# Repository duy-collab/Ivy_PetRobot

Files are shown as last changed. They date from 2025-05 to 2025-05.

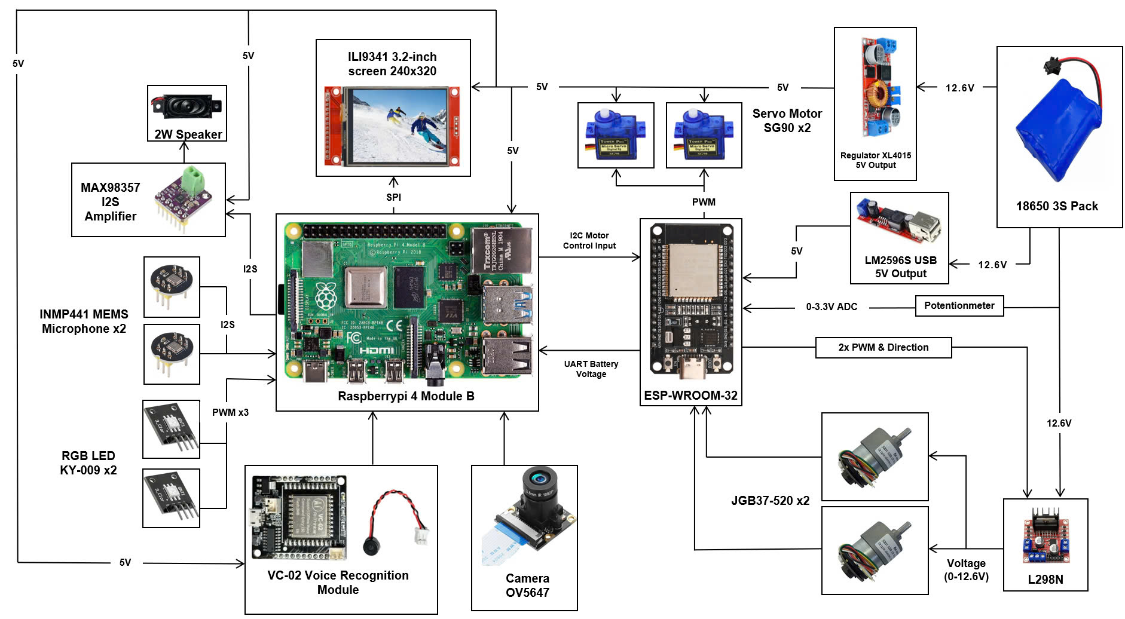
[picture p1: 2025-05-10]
HARDWARE SYSTEM.jpg

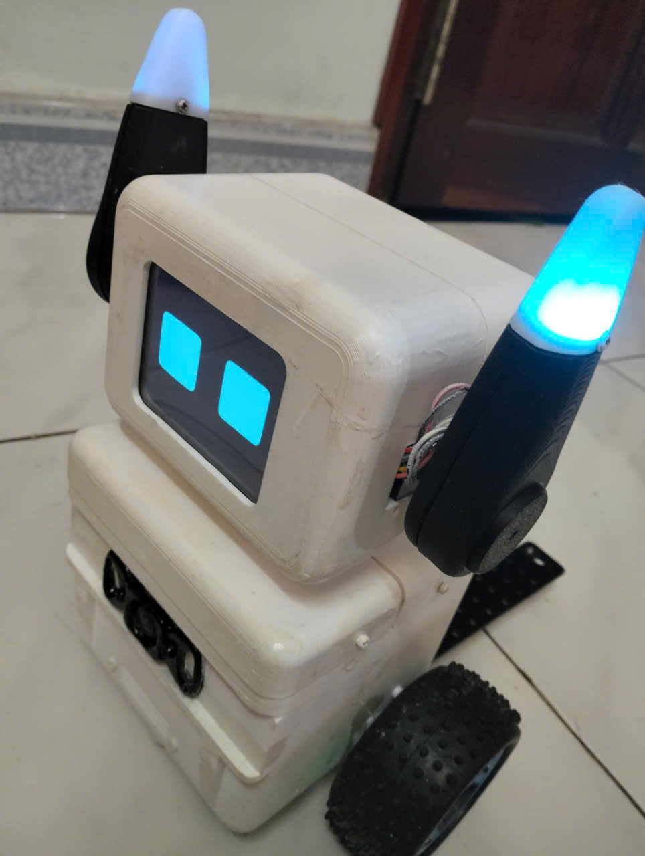
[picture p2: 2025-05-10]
Ivy_Pics/1.jpg

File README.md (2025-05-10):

# Ivy_PetRobot

Ivy_PetRobot is an interactive AI-powered pet robot designed to engage with users through voice, facial recognition, and dynamic behaviors. It brings personality to robotics with a focus on emotional expression and smart interaction.

## Features

- 🎤 Voice recognition using Whisper
- 🗣️ Speech synthesis with natural voice
- 🧠 AI-powered conversation using OpenAI API
- 📷 Image recognition and scene description
- 😺 Facial emotion display via LCD and LED
- 🛞 Motor control for mobility and animation
- 🕹️ ESP32 & Raspberry Pi integration
- 📡 MQTT cloud communication with HiveMQ
- 📁 I2C communication for command synchronization

## Technologies Used

- Raspberry Pi OS Bullseye
- ESP32 microcontroller
- INMP441 microphone (I2S)
- MAX98357A speaker amp (I2S)
- ILI9341 / ST7796 LCD with GT911 touch
- OpenAI Whisper and GPT APIs
- HiveMQ MQTT for IoT data streaming
- Python, C++ (Arduino), Bash

## Repository Structure

/Ivy_PetRobot
├── raspberry_pi/ # Main AI logic, image processing, audio I/O

├── esp32/ # Display, motors, expression handling

├── arduino_nano/ # Optional: audio capture and I2C transmission

├── assets/ # Face expression images, sound files

├── docs/ # Reports and design documentation

└── README.md

## Credits

Final year thesis project by Luong Ho Khanh Duy, Student ID 2113013 and Tran Kim Khanh, Student ID 2113717 — Department of Electrical Engineering, Ho Chi Minh City University of Technology (HCMUT).

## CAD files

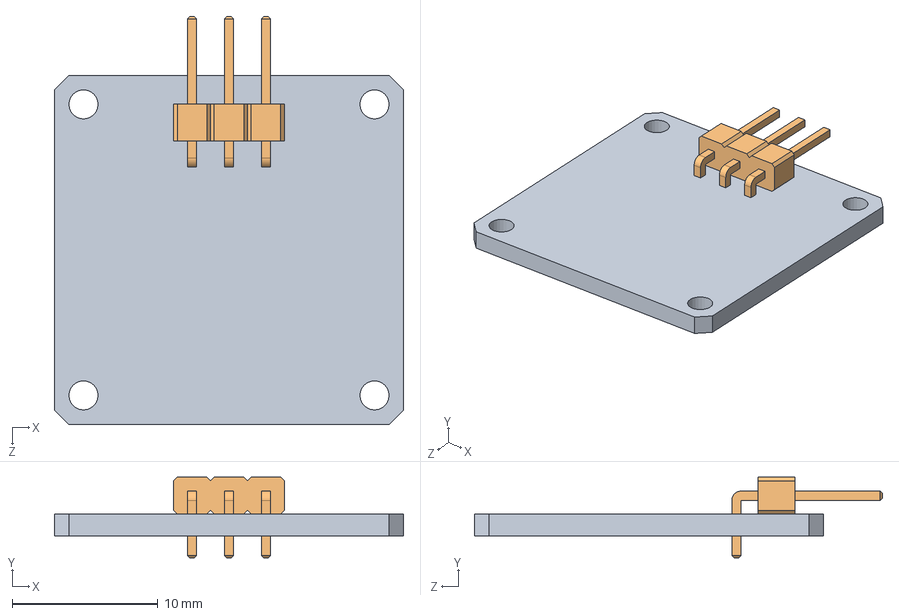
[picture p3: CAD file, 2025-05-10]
Ivy_SolidWorks/HEAD/TTP223B_with_header.SLDASM
24.0 x 5.54 x 28.0 mm
TTP223B
PinHeader_1x03_P2.54mm_Horizontal

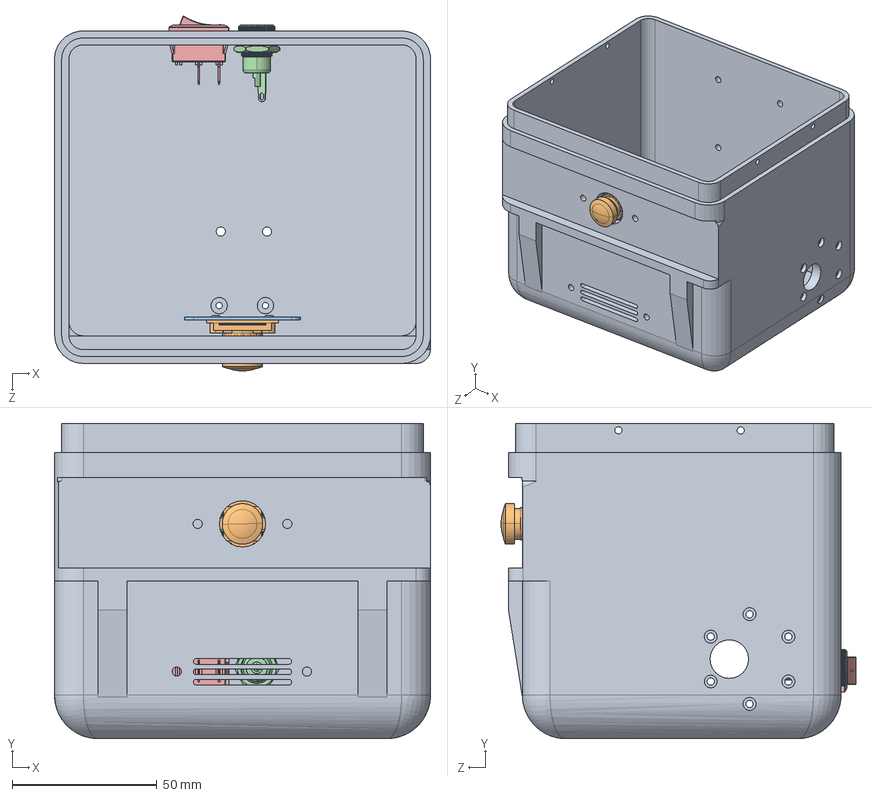
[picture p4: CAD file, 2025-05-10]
Ivy_SolidWorks/BODY/Body_Full.SLDASM
130.0 x 109.0 x 122.7 mm
camera_OV5647
camera_OV5647_mount
charging_port_5.5_2.1_DC
KCD1-101_2pin

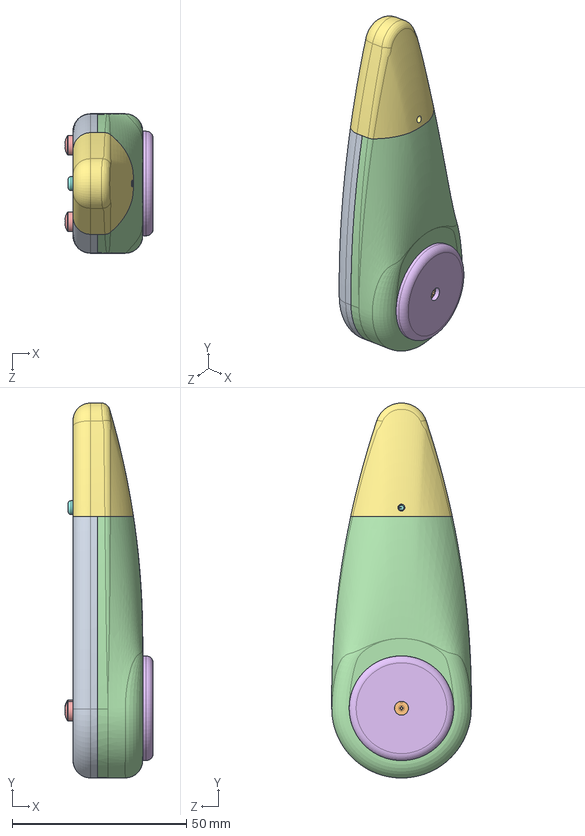
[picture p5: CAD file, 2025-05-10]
Ivy_SolidWorks/HEAD/EAR/EAR_FULL.SLDASM
25.4 x 107.5 x 40.0 mm
Inside_Ear
new_ear_pcb
spacer_10mm x 2
Outside_Ear
pan head cross recess screw_iso x 4
new_mic_cover
Top_Ear
pan head tapping screw_am

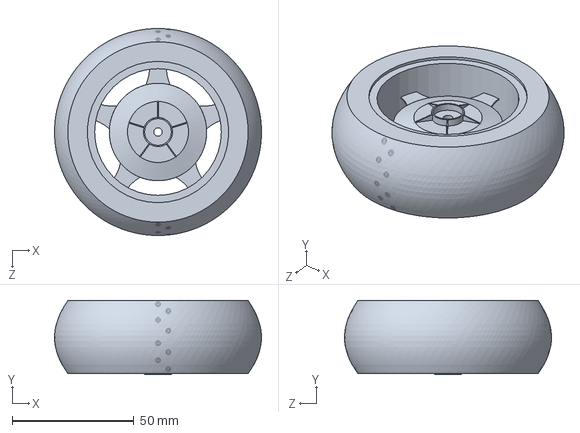
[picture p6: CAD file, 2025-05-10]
Ivy_SolidWorks/WHEEL/Wheel_assem.SLDASM
85.0 x 30.4 x 85.0 mm
85mm_Wheel
wheel_adapter

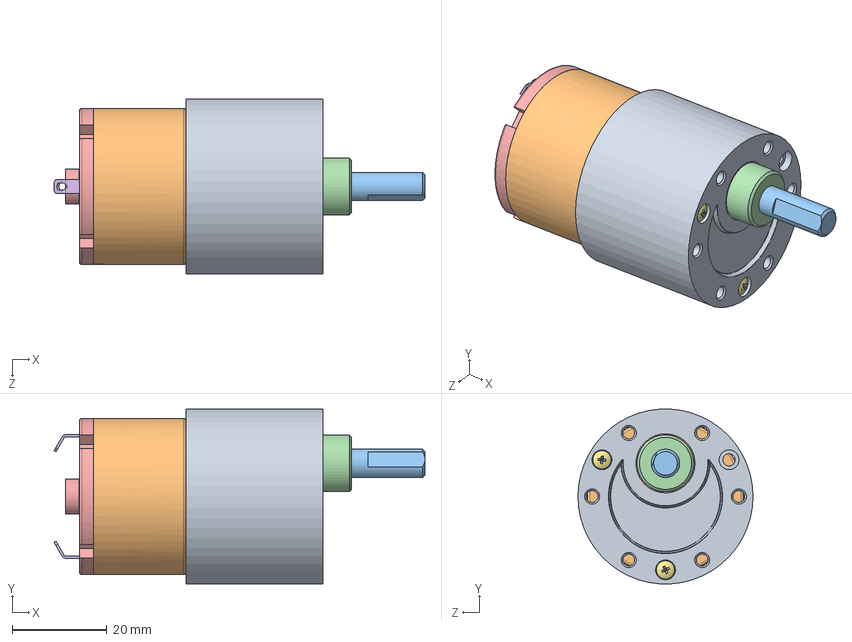
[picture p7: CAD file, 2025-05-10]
Ivy_SolidWorks/WHEEL/JGA37_520.SLDASM
78.4 x 36.9 x 37.0 mm
GEARED BODY, MOTOR, JGB37-520
DC MOTOR, JGB37-520
MOTOR SHAFT, JGB37-520
SHAFT COUPLER, JGB37-520
PLASTIC COVER, DC MOTOR, JGB37-520
CONNECTION, DC MOTOR, JGB37-520 x 2
pan cross head_am x 2

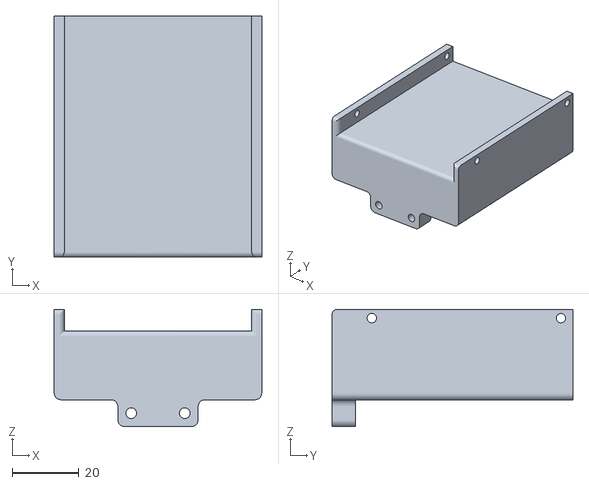
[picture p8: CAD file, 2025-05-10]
Ivy_PRINT_3D/power_shell.STL
62.0 x 72.0 x 35.0

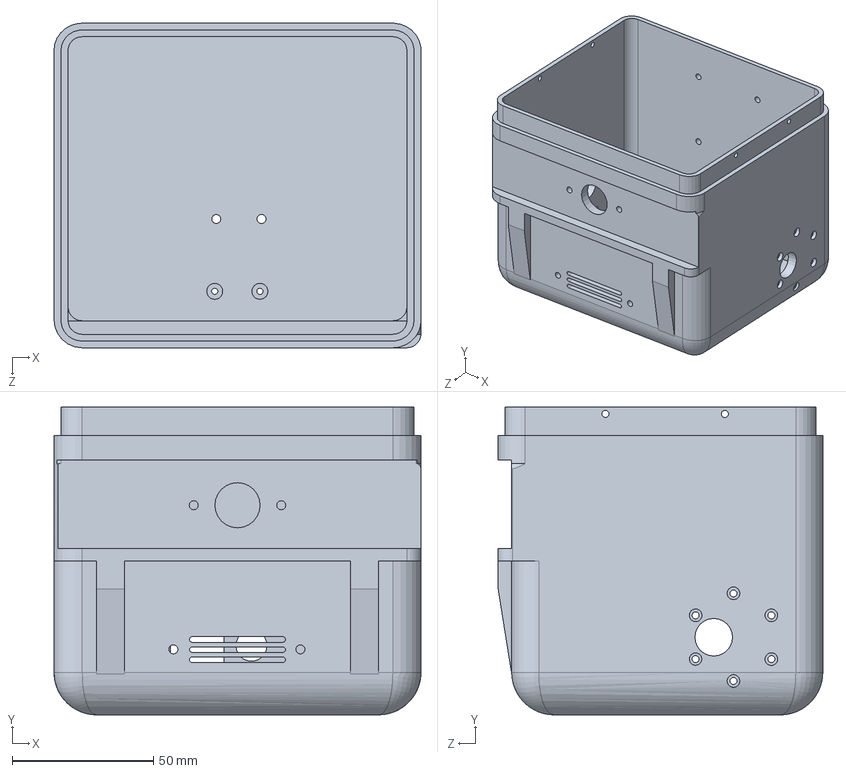
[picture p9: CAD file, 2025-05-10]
Ivy_SolidWorks/BODY/Body.SLDPRT
130.0 x 109.0 x 115.0 mm

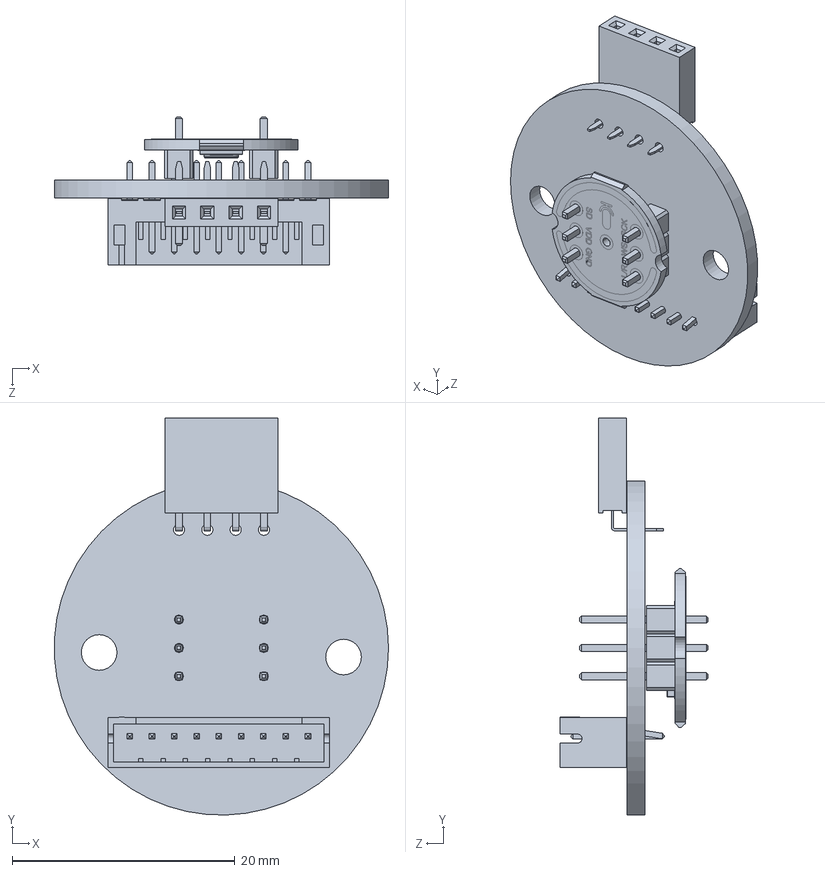
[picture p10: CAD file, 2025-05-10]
Ivy_SolidWorks/HEAD/EAR/new_ear_pcb.SLDPRT
30.0 x 35.6 x 13.3 mm

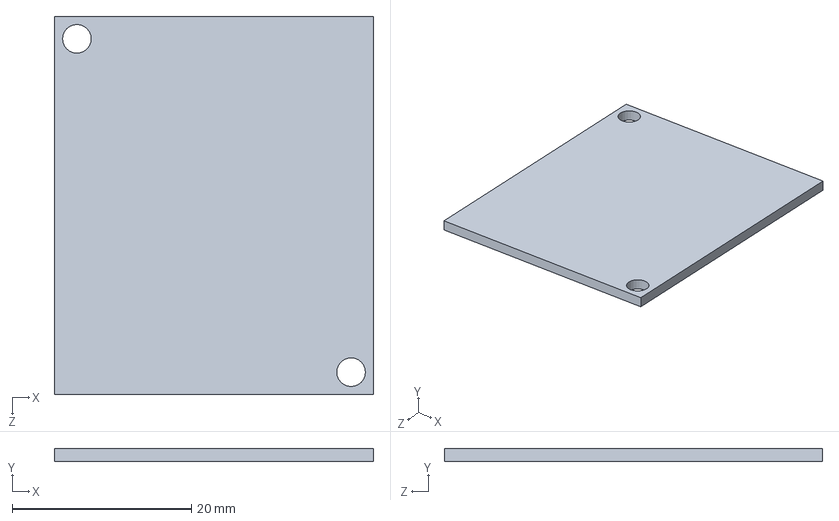
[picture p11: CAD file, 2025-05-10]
Ivy_SolidWorks/HEAD/VC-02.SLDPRT
35.6 x 1.50 x 42.2 mm

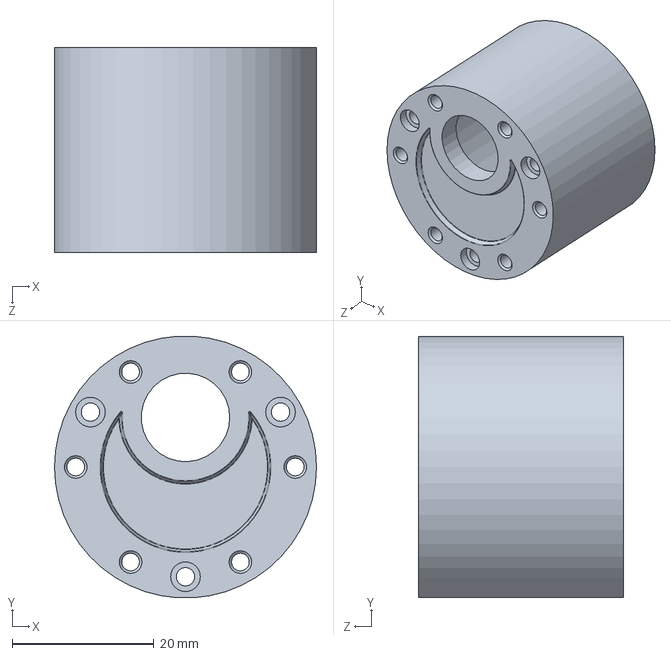
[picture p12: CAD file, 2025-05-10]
Ivy_SolidWorks/WHEEL/GEARED BODY, MOTOR, JGB37-520.SLDPRT
37.0 x 36.9 x 29.0 mm

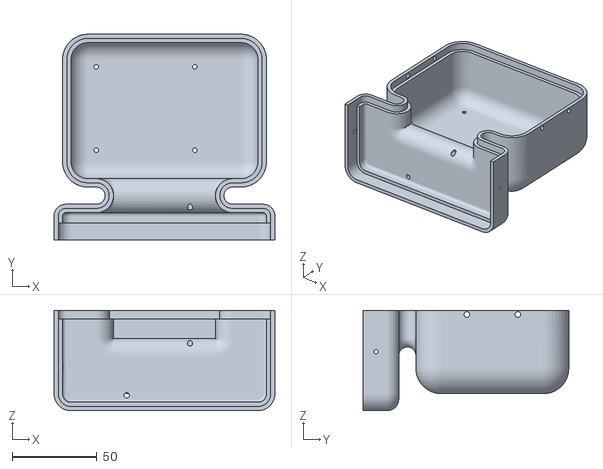
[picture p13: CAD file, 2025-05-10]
Ivy_PRINT_3D/BackHead.STL
130.0 x 121.0 x 59.1

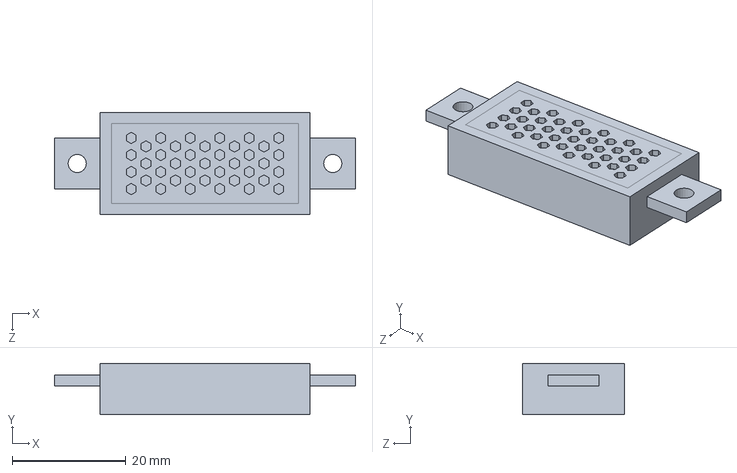
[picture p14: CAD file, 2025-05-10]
Ivy_SolidWorks/BODY/speaker_2w.SLDPRT
53.0 x 9.00 x 18.0 mm

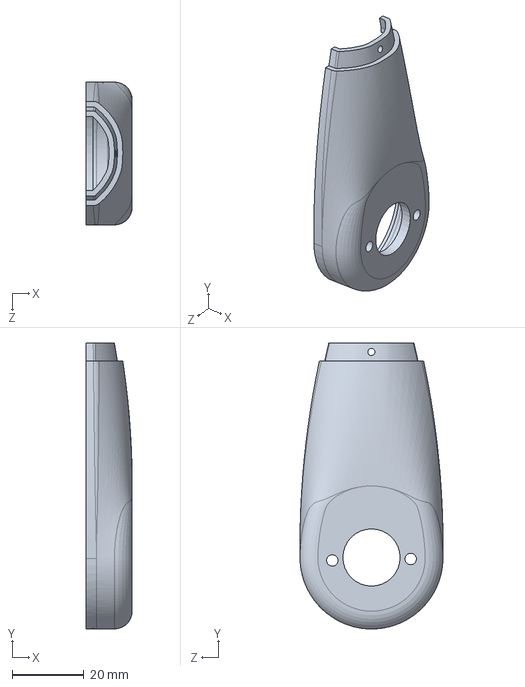
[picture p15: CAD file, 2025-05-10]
Ivy_SolidWorks/HEAD/EAR/Outside_Ear.SLDPRT
13.0 x 80.0 x 40.0 mm

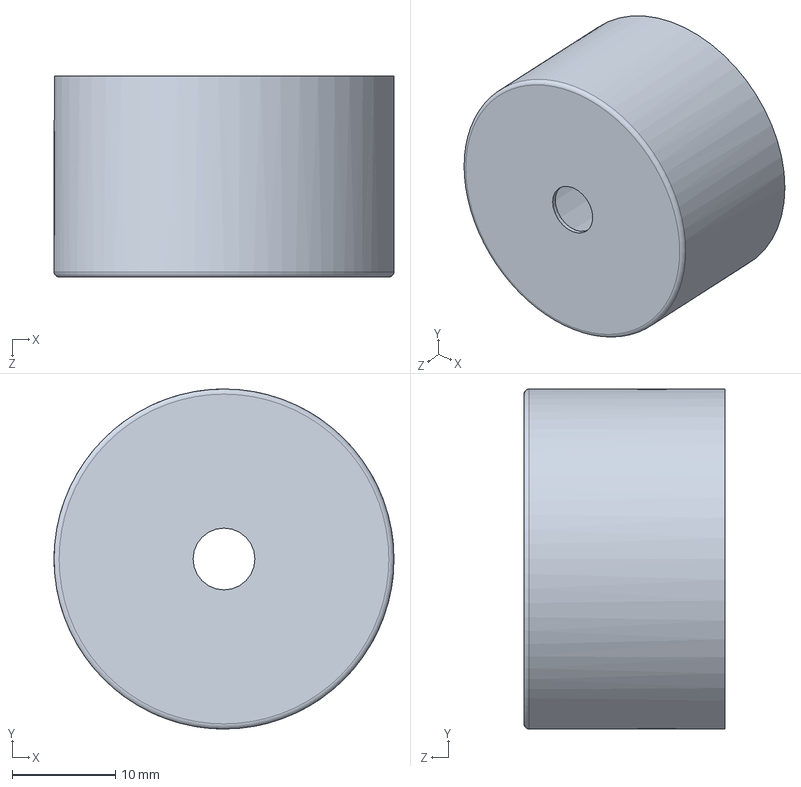
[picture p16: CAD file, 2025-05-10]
Ivy_SolidWorks/WHEEL/DC MOTOR, JGB37-520.SLDPRT
33.0 x 33.0 x 19.5 mm

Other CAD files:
Ivy_SolidWorks/BODY/Battery/power_shell.SLDPRT
Ivy_PRINT_3D/camera_OV5647_mount.STL
Ivy_SolidWorks/HEAD/EAR/Top_Ear.SLDPRT
Ivy_SolidWorks/HEAD/PinHeader_1x03_P2.54mm_Horizontal.SLDPRT
Ivy_PRINT_3D/Body_ver2_22-9.STL
Ivy_PRINT_3D/FrontHead.STL
Ivy_PRINT_3D/TAI_NGOAI.STL
Ivy_PRINT_3D/TAI_TOP.STL
Ivy_PRINT_3D/TAI_TRONG.STL
Ivy_PRINT_3D/bowtie.STL
Ivy_PRINT_3D/new_mic_cover.STL
Ivy_SolidWorks/BODY/L298N.SLDPRT
Ivy_SolidWorks/BODY/bowtie.SLDPRT
Ivy_SolidWorks/BODY/camera_OV5647.SLDPRT
Ivy_SolidWorks/BODY/camera_OV5647_mount.SLDPRT
Ivy_SolidWorks/BODY/caster_ball.SLDPRT
Ivy_SolidWorks/BODY/charging_port_5.5_2.1_DC.SLDPRT
Ivy_SolidWorks/HEAD/Back_Head.SLDPRT
Ivy_SolidWorks/HEAD/EAR/Inside_Ear.SLDPRT
Ivy_SolidWorks/HEAD/EAR/ear_mica_holder.SLDPRT
Ivy_SolidWorks/HEAD/EAR/new_mic_cover.SLDPRT
Ivy_SolidWorks/HEAD/EAR/sg90_horn.SLDPRT
Ivy_SolidWorks/HEAD/EAR/spacer_10mm.SLDPRT
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

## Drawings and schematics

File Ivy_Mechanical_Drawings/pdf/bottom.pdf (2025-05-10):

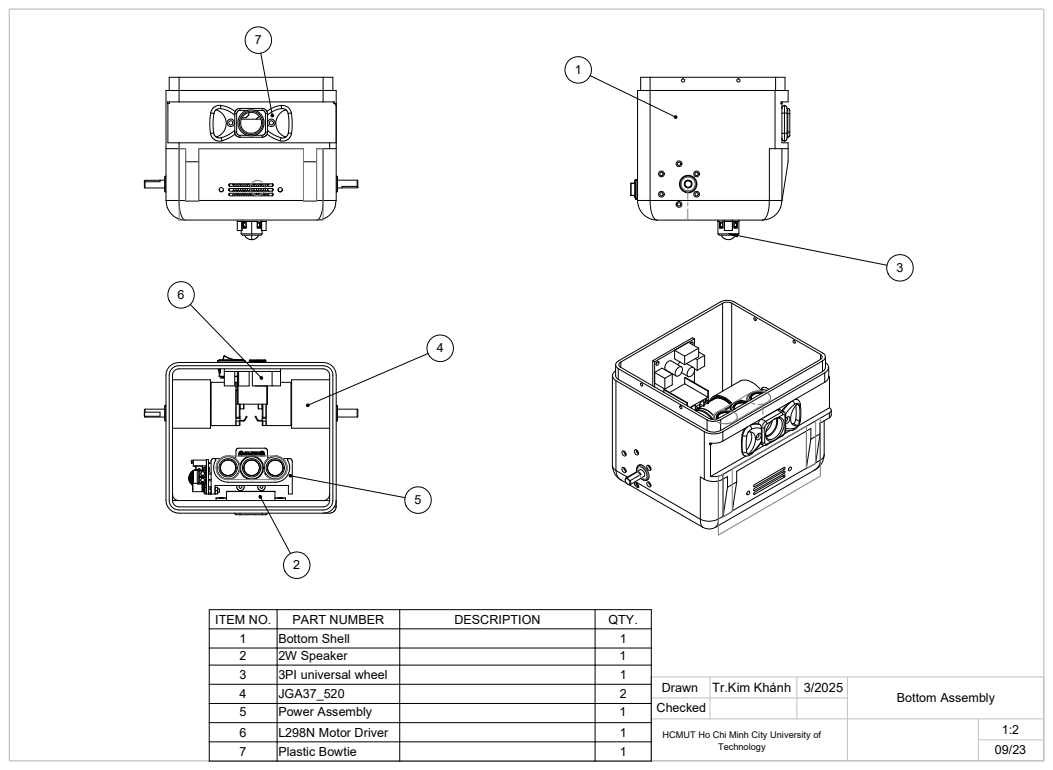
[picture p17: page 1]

ITEM NO. | PART NUMBER | DESCRIPTION | QTY.
1 | Bottom Shell | | 1
2 | 2W Speaker | | 1
3 | 3PI universal wheel | | 1
4 | JGA37_520 | | 2
5 | Power Assembly | | 1
6 | L298N Motor Driver | | 1
7 | Plastic Bowtie | | 1 | 09/23

Drawn | Tr.Kim Khánh | 3/2025 | Bottom Assembly
Checked

HCMUT Ho Chi Minh City University of Technology | | 1:2

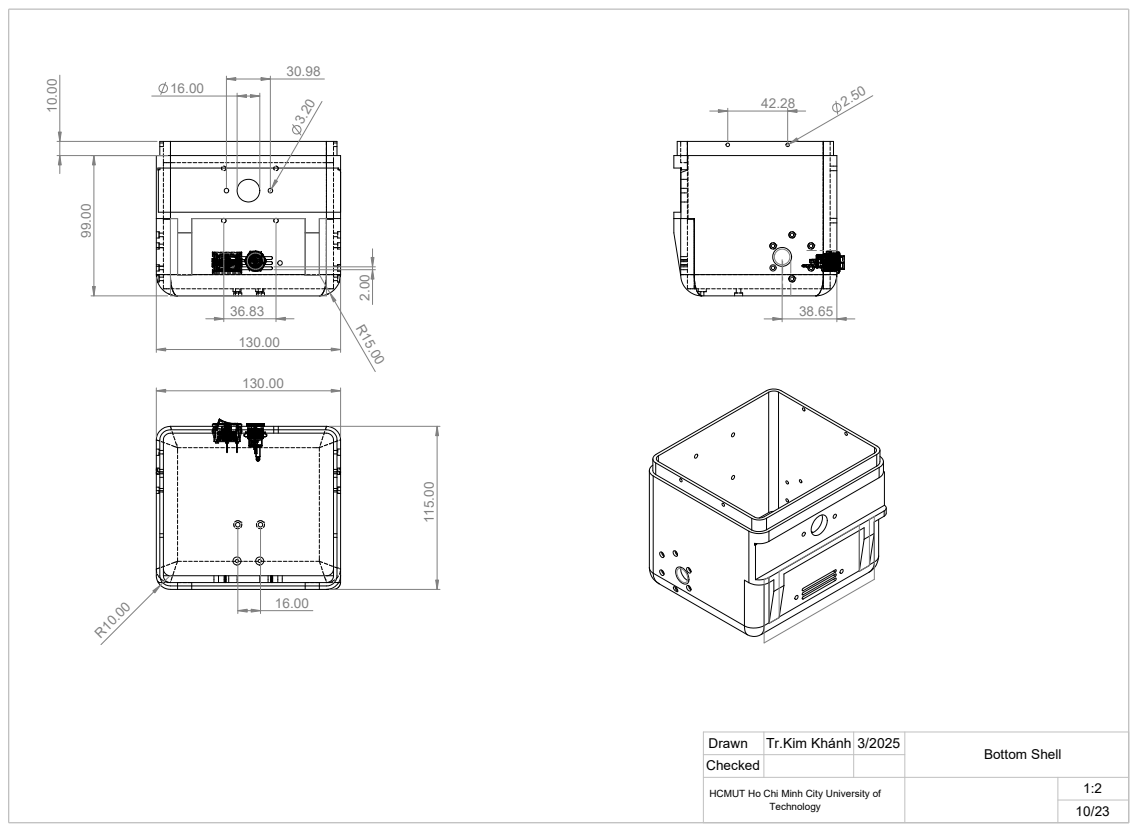
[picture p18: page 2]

Drawn | Tr.Kim Khánh | 3/2025 | Bottom Shell
Checked

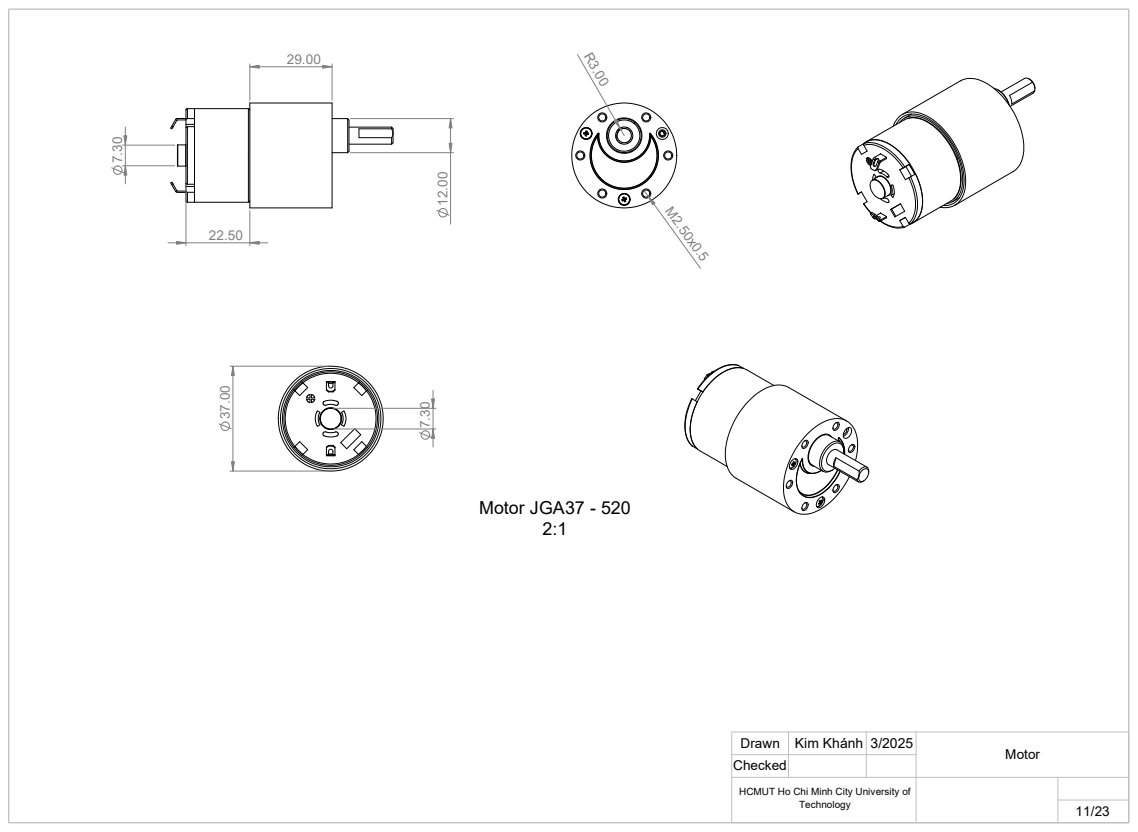
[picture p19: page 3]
Technology; Motor JGA37 - 520

Drawn | Kim Khánh | 3/2025 | Motor
Checked

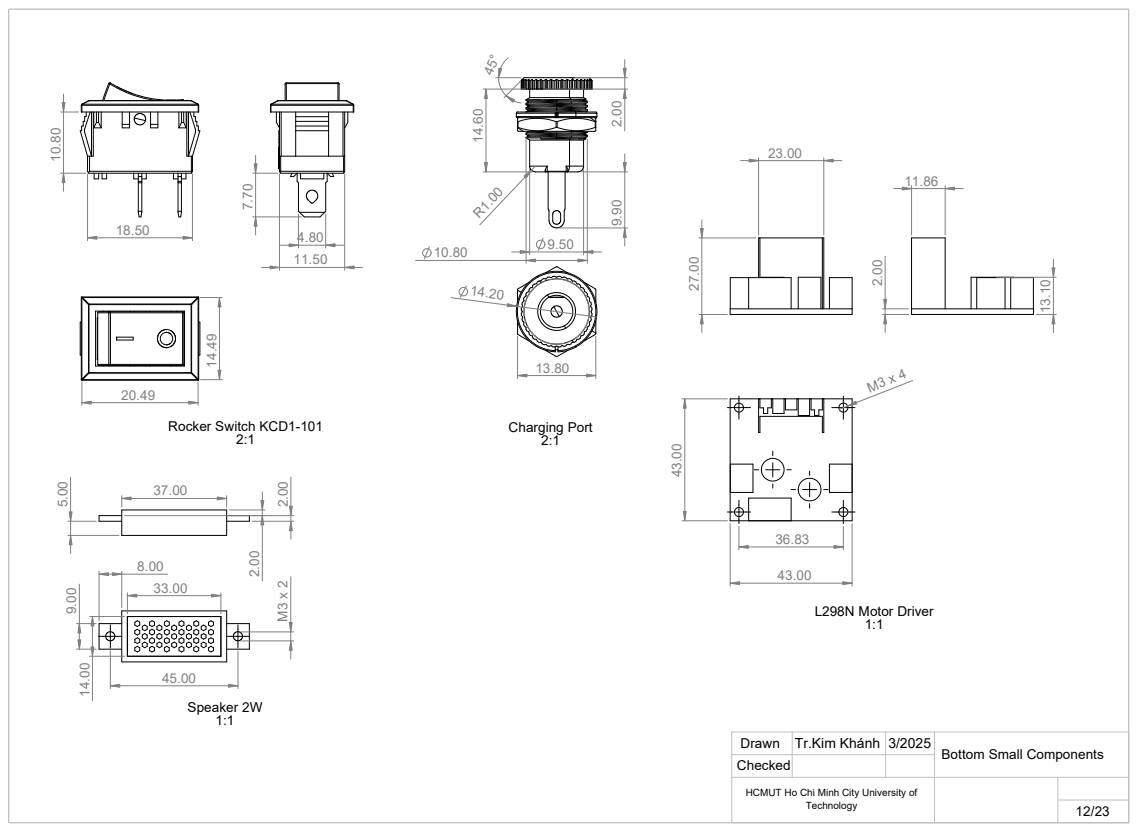
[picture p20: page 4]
Technology; Speaker 2W 1:1; L298N Motor Driver 1:1; Rocker Switch KCD1-101 2:1; Charging Port 2:1

Drawn | Tr.Kim Khánh | 3/2025 | Bottom Small Components
Checked

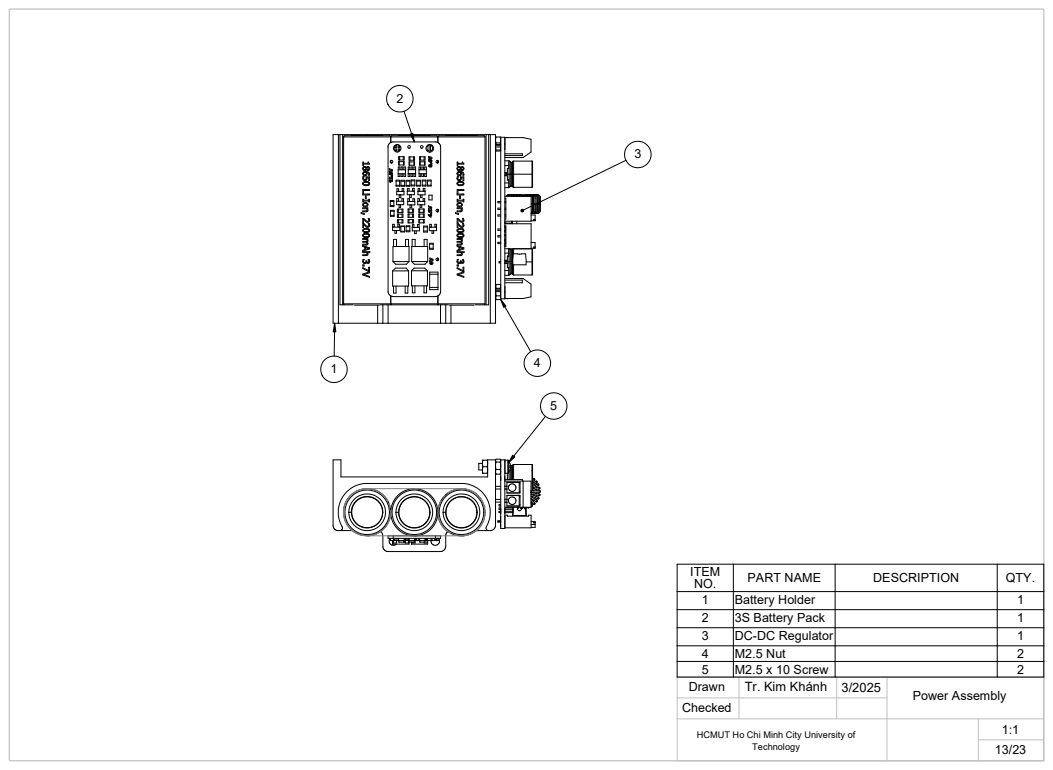
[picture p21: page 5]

ITEM NO. | PART NAME | DESCRIPTION | QTY.

1 | Battery Holder | | 1
2 | 3S Battery Pack | | 1
3 | DC-DC Regulator | | 1
4 | M2.5 Nut | | 2
5 | M2.5 x 10 Screw | | 2
Drawn | Tr. Kim Khánh | 3/2025 | Power Assembly
Checked

1:1 ⁶⁴.80

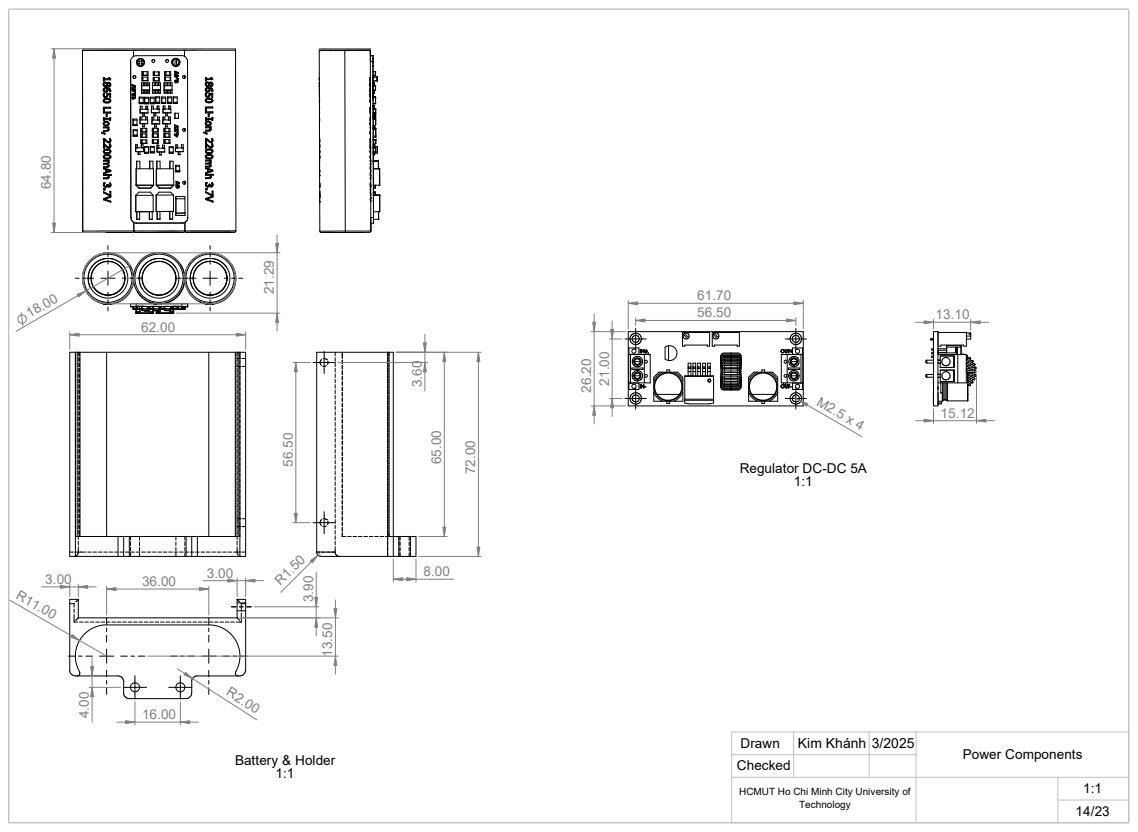
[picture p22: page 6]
Battery & Holder

Regulator DC-DC 5A

Drawn | Kim Khánh | 3/2025 | Power Components
Checked

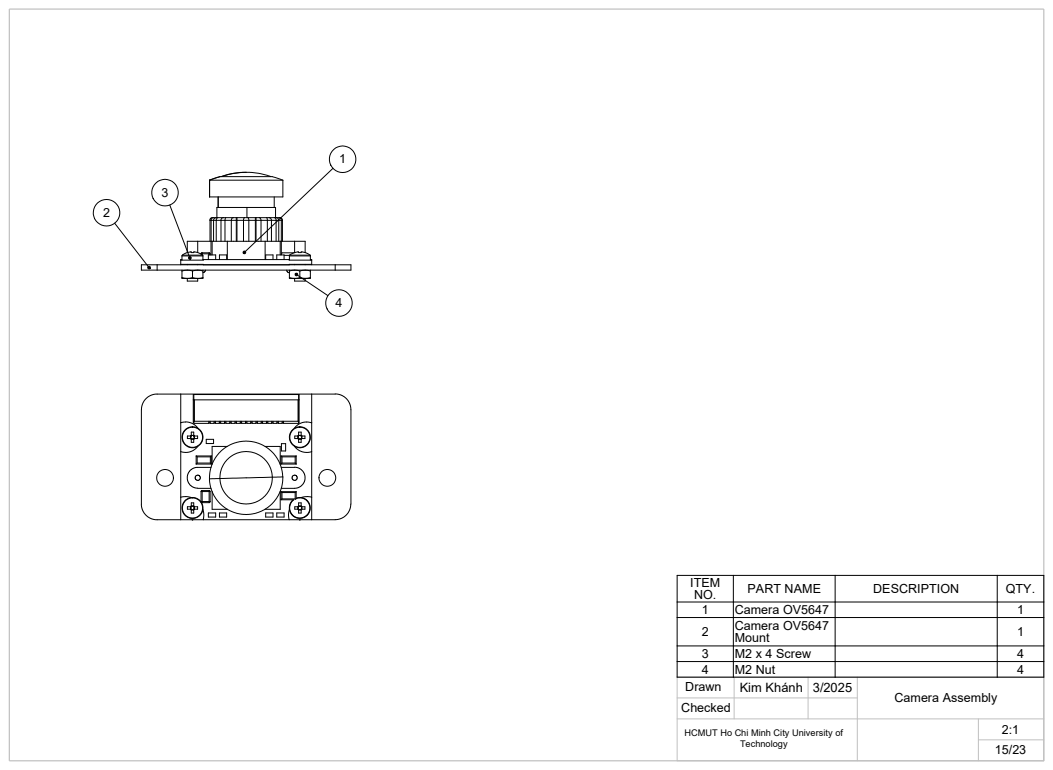
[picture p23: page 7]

ITEM NO. | PART NAME | DESCRIPTION | QTY.

1 | Camera OV5647 | | 1
2 Camera OV5647 | Mount | | 1

3 | M2 x 4 Screw | | 4
4 | M2 Nut | | 4
Drawn | Kim Khánh | 3/2025 | Camera Assembly
Checked

# 30.98 ²⁴.00 3.00

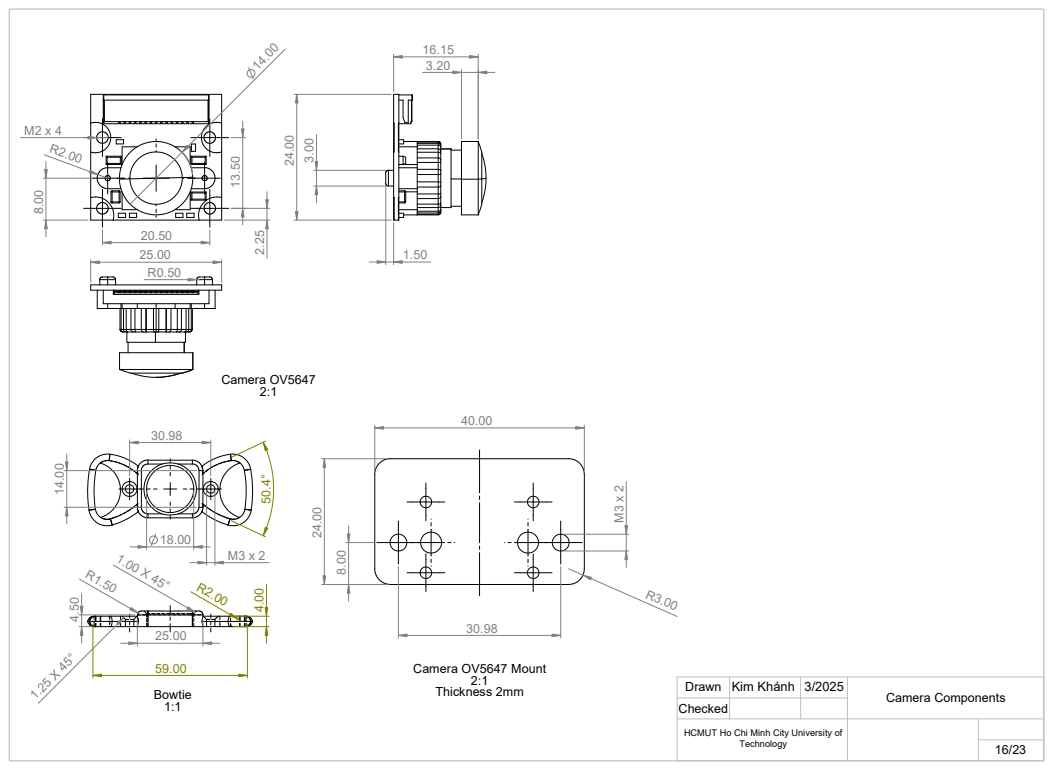
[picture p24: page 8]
Drawn; Checked; Kim Khánh; Camera Components; Technology; Camera OV5647 Mount 2:1 Thickness 2mm; Camera OV5647 2:1; Bowtie

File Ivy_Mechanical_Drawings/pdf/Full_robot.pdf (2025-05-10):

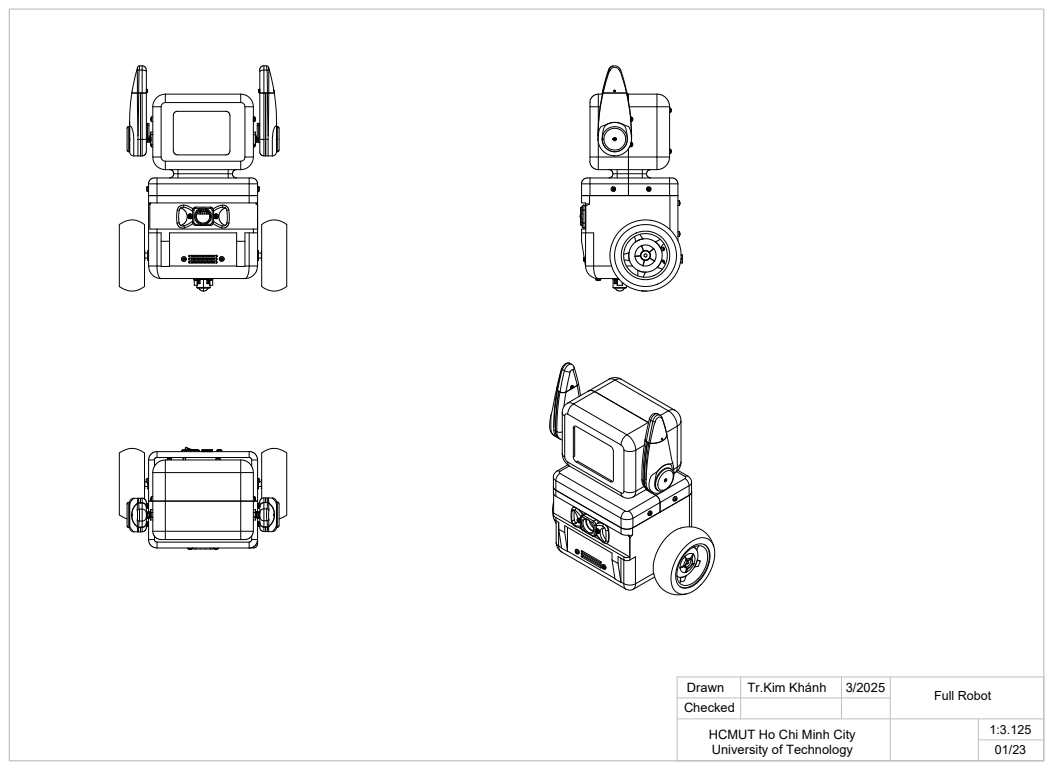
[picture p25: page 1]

Drawn | Tr.Kim Khánh | 3/2025 | Full Robot
Checked
HCMUT Ho Chi Minh City University of Technology | | 1:3.125

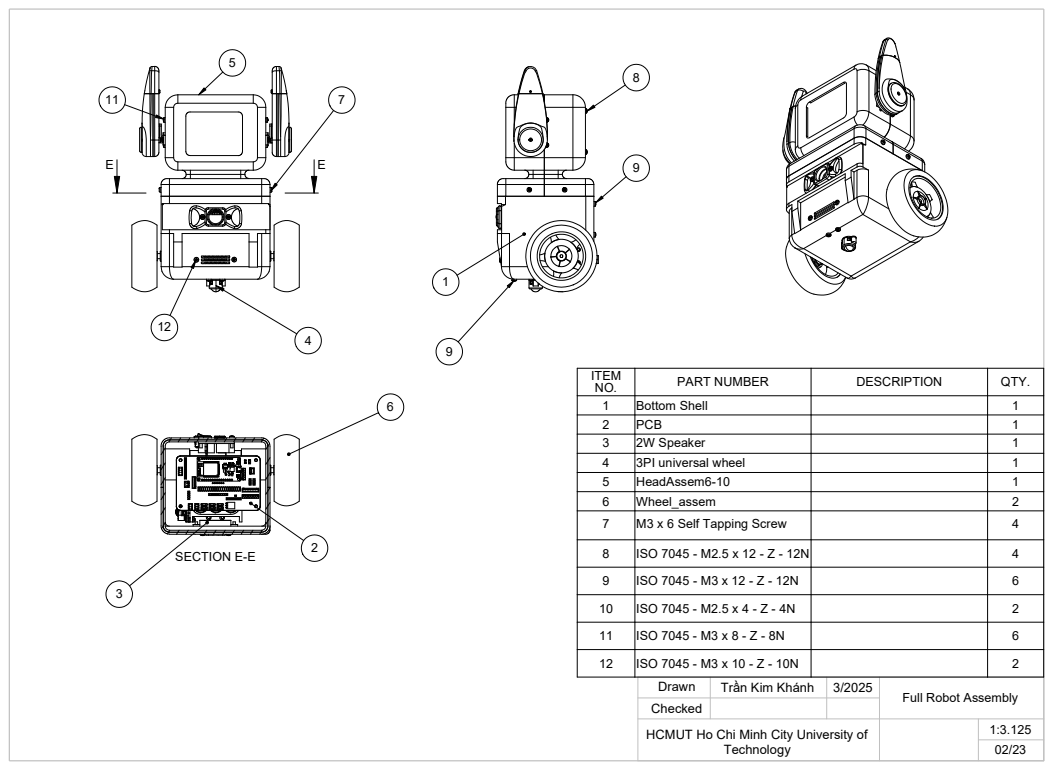
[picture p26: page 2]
ITEM; PART NUMBER; DESCRIPTION; QTY.; Bottom Shell; PCB; 2W Speaker; 3PI universal wheel; HeadAssem6-10; Wheel_assem; M3 x 6 Self Tapping Screw; ISO 7045 - M2.5 x 12 - Z - 12N; ISO 7045 - M3 x 12 - Z - 12N; ISO 7045 - M2.5 x 4 - Z - 4N; ISO 7045 - M3 x 8 - Z - 8N; ISO 7045 - M3 x 10 - Z - 10N; SECTION E-E

Drawn | Trần Kim Khánh | 3/2025 | Full Robot Assembly
Checked
HCMUT Ho Chi Minh City University of Technology | | 1:3.125

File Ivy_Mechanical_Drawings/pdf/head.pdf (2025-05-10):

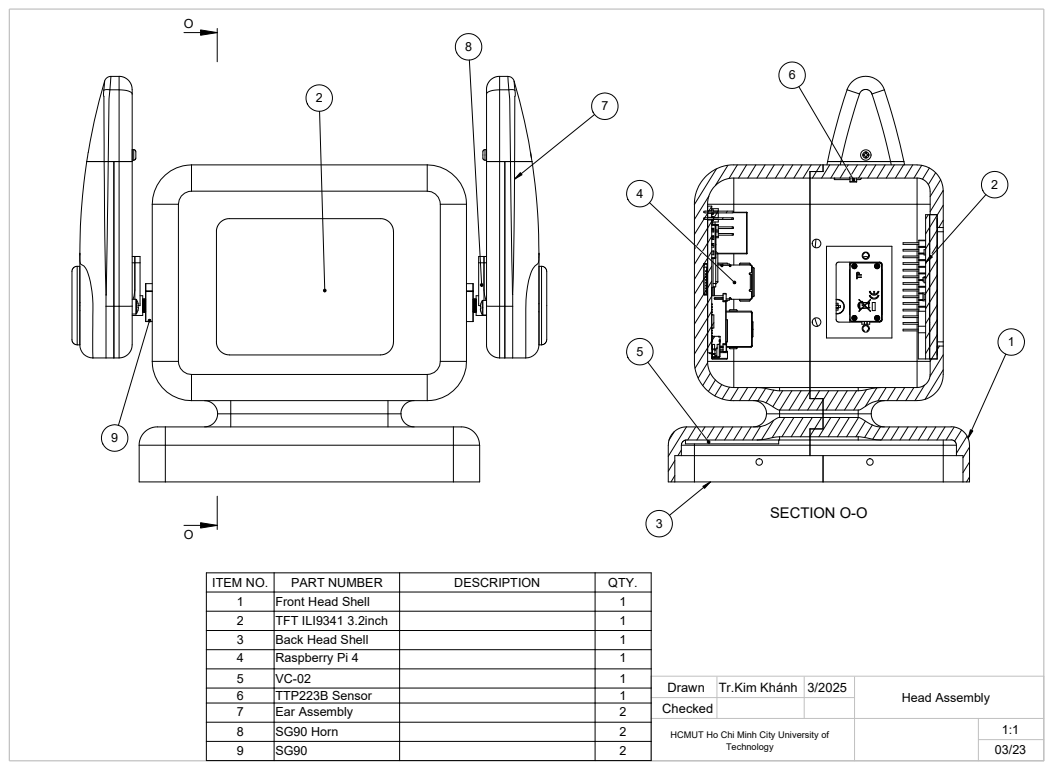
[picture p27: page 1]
SECTION O-O

ITEM NO. | PART NUMBER | DESCRIPTION | QTY.
1 | Front Head Shell | | 1
2 | TFT ILI9341 3.2inch | | 1
3 | Back Head Shell | | 1
4 | Raspberry Pi 4 | | 1
5 | VC-02 | | 1
6 | TTP223B Sensor | | 1
7 | Ear Assembly | | 2
8 | SG90 Horn | | 2
9 | SG90 | | 2 | 03/23

Drawn | Tr.Kim Khánh | 3/2025 | Head Assembly
Checked
HCMUT Ho Chi Minh City University of Technology | | 1:1

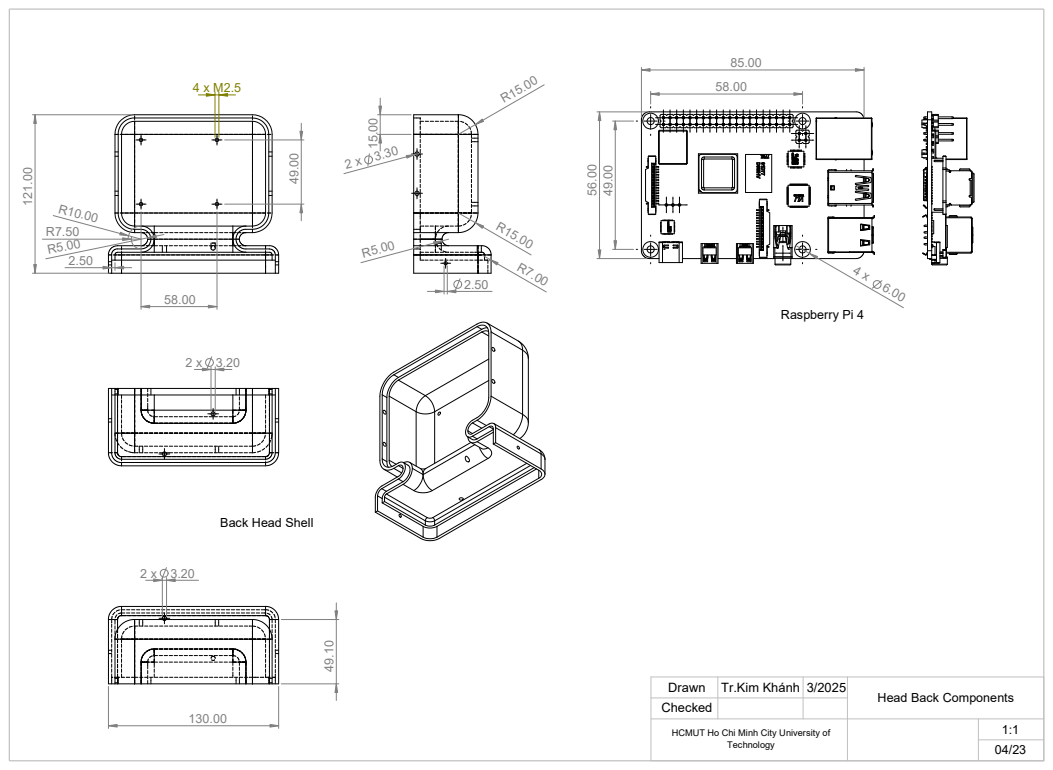
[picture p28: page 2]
Raspberry Pi 4; Back Head Shell; 58.00 ¹²¹.00

Drawn | Tr.Kim Khánh | 3/2025 | Head Back Components
Checked

Technology; TFT ILI9341 3.2-Inch Screen 1:1; TTP223B

Head Front Shell

Drawn | Kim Khánh | 3/2025 | Head Front Components
Checked

SECTION A-A

ITEM NO. | PART NUMBER | DESCRIPTION | QTY.

1 | Inner Ear Shell | | 1
2 | Ear PCB | | 1
3 | Brass Spacer 10mm | | 2

4 | Outer Ear Shell | | 1
5 | M3 x 5 Screw | | 2
6 | M3 x 10 Screw | | 2
7 | Mic Cover | | 1
8 | Ear Top Cover | | 1
9 M2 Self-Tapping | Screw | | 1

Drawn | Kim Khánh | 3/2025 | Ear Assembly
Checked

Technology; SG90 Servo 1:1

Drawn | Kim Khánh | 3/2025 | Ear Actuator Components
Checked

Technology; Ear PCB 1:1; Spacer 10mm 5:1 Length 10mm

Inner Ear Shell

Top Ear Shell

Outer Ear Shell

Drawn | Kim Khánh | 3/2025 | Ear Components
Checked




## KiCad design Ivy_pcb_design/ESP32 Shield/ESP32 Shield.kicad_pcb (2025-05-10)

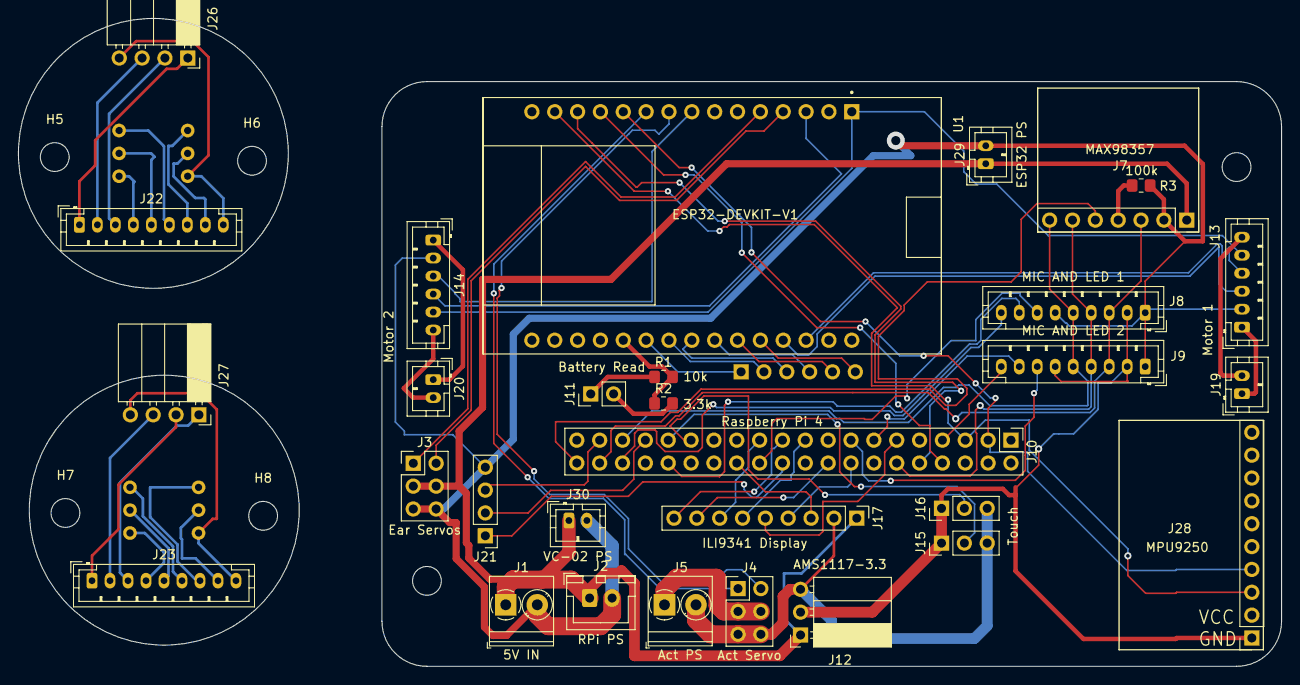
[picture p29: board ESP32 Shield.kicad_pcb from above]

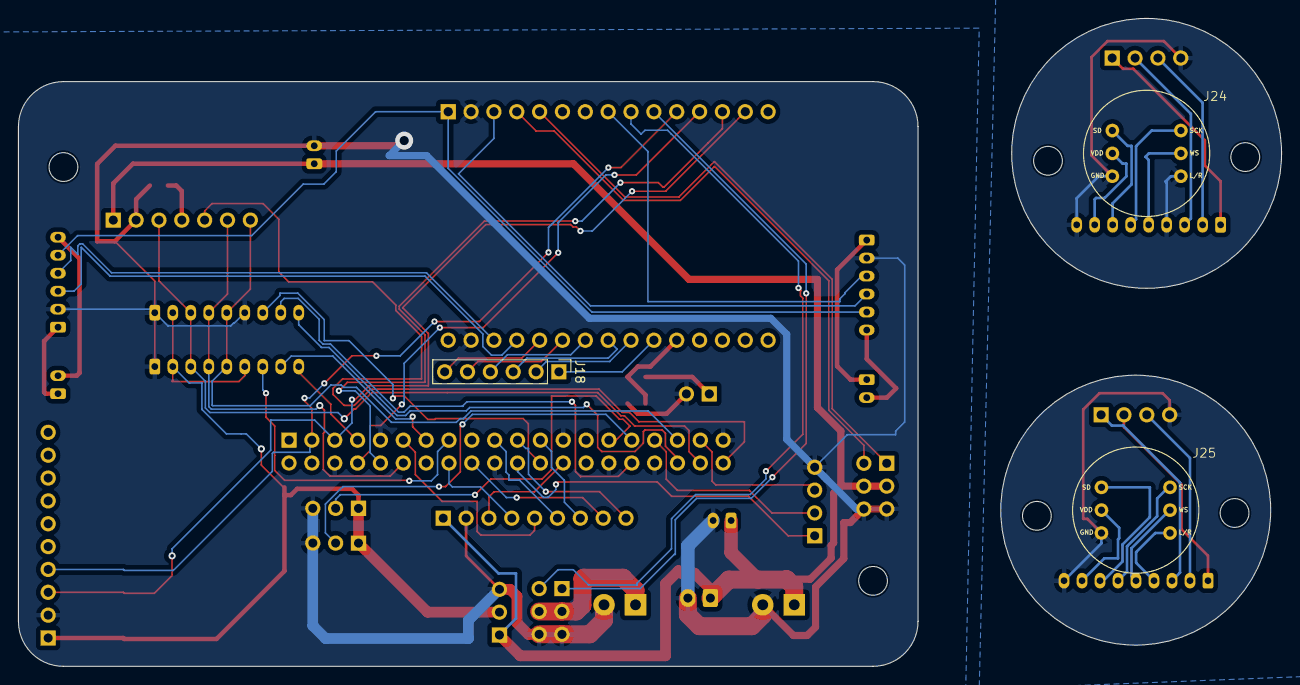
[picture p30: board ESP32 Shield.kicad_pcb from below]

Board: 2 copper layers, 100.0 x 65.0 mm, 39 parts (3 on the bottom side), 65 nets.

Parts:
H2, H3, H5, H6, H7, H8: MountingHole; MountingHole_3.2mm_M3
J1: 5V IN; TerminalBlock_Phoenix_PT-1,5-2-3.5-H_1x02_P3.50mm_Horizontal
J2: RPi PS; JST_XH_B2B-XH-A_1x02_P2.50mm_Vertical
J3: Ear Servos; PinHeader_2x03_P2.54mm_Vertical
J4: Act Servo; PinHeader_2x03_P2.54mm_Vertical
J5: Act PS; TerminalBlock_Phoenix_PT-1,5-2-3.5-H_1x02_P3.50mm_Horizontal
J7: MAX98357; PinSocket_1x07_P2.54mm_Vertical
J8: MIC AND LED 1; JST_PH_B9B-PH-K_1x09_P2.00mm_Vertical
J9: MIC AND LED 2; JST_PH_B9B-PH-K_1x09_P2.00mm_Vertical
J10: Raspberry Pi 4; PinHeader_2x20_P2.54mm_Vertical
J11: Battery Read; PinHeader_1x02_P2.54mm_Vertical
J12: AMS1117-3.3; PinSocket_1x03_P2.54mm_Horizontal
J13: Motor 1; JST_PH_B6B-PH-K_1x06_P2.00mm_Vertical
J14: Motor 2; JST_PH_B6B-PH-K_1x06_P2.00mm_Vertical
J15: Touch; PinHeader_1x03_P2.54mm_Vertical
J16: Touch 3; PinHeader_1x03_P2.54mm_Vertical
J17: ILI9341 Display; PinHeader_1x09_P2.54mm_Vertical
J18: L298N; PinHeader_1x06_P2.54mm_Vertical
J19: L298N-Motor 1; JST_PH_B2B-PH-K_1x02_P2.00mm_Vertical
J20: L298N-Motor 2; JST_PH_B2B-PH-K_1x02_P2.00mm_Vertical
J21: VC-02; PinHeader_1x04_P2.54mm_Vertical
J22: MIC AND LED 1 - EAR; JST_PH_B9B-PH-K_1x09_P2.00mm_Vertical
J23: MIC AND LED 2 - EAR; JST_PH_B9B-PH-K_1x09_P2.00mm_Vertical
J24: MIC 1; INMP441
J25: MIC 2; INMP441
J26: LED 1; PinSocket_1x04_P2.54mm_Horizontal
J27: LED 2; PinSocket_1x04_P2.54mm_Horizontal
J28: MPU9250; PinSocket_1x10_P2.54mm_Vertical
J29: ESP32 PS; JST_PH_B2B-PH-K_1x02_P2.00mm_Vertical
J30: VC-02 PS; JST_PH_B2B-PH-K_1x02_P2.00mm_Vertical
R1: 10k; R_0805_2012Metric_Pad1.20x1.40mm_HandSolder
R2: 3.3k; R_0805_2012Metric_Pad1.20x1.40mm_HandSolder
R3: 100k; R_0805_2012Metric_Pad1.20x1.40mm_HandSolder
U1: ESP32-DEVKIT-V1; MODULE_ESP32_DEVKIT_V1

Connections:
+3.3V: J13.5, J14.5, U1.1 (3V3)
+3.3VA: J8.2, J9.2, J9.6, J12.2, J15.1, J16.1, J28.1
+3.3VRP: J10.1, J10.17
+3.3V_EAR: J22.8, J23.4, J23.8, J24.2, J25.2, J25.6
+5V: J1.1, J2.1, J3.3, J3.4, J7.1, J12.1, J17.1, J29.1, J30.1
+5VRP: J10.2, J10.4
+7.5V: J4.3, J4.4, J5.1
+12V: J11.1, R1.1
/BCLK: J7.6, J8.4, J9.4, J10.12
/BLUE1: J8.9, J10.36
/BLUE1_EAR: J22.1, J26.1
/BLUE2: J9.7, J10.15
/BLUE2_EAR: J23.3, J27.1
/Battery ADC: R1.2, R2.1, U1.20 (D35)
/CS: J10.26, J17.3
/DC/RS: J10.11, J17.5
/DIN: J7.5, J10.40
/ENA: J18.1, U1.21 (D32)
/ENB: J18.6, U1.26 (D14)
/GAIN: J7.4, R3.1
/GPIO2: J10.3, J28.4, U1.11 (D21)
/GPIO3: J10.5, J28.3, U1.14 (D22)
/GPIO4: J9.9, J10.7
/GPIO5: J10.29, J16.2
/GPIO6: J10.31, J15.2
/GPIO8: J8.7, J10.24
/GPIO9: J10.21, J17.9
/GPIO10: J10.19, J17.6
/GPIO11: J10.23, J17.7
/GPIO12: J8.8, J10.32
/GPIO13: J10.33, J21.2
/GPIO14: J10.8, U1.12 (RX0)
/GPIO15: J10.10, U1.13 (TX0)
/GPIO19: J7.7, J8.5, J9.5, J10.35
/GPIO20: J7.3, J8.3, J9.3, J10.38
/GPIO23: J10.16, J17.4
/GPIO24: J10.18, J17.8
/GPIO25: J10.22, J21.1
/GPIO26: J10.37, J21.3
/GPIO27: J9.8, J10.13
/GREEN1_EAR: J22.2, J26.3
/GREEN2_EAR: J23.2, J27.3
/IN1: J18.2, U1.22 (D33)
/IN2: J18.3, U1.23 (D25)
/IN3: J18.4, U1.24 (D26)
/IN4: J18.5, U1.25 (D27)
/Motor 1 (C1): J13.3, U1.27 (D12)
/Motor 1 (C2): J13.4, U1.28 (D13)
/Motor 1 (M1): J13.1, J19.1
/Motor 1 (M2): J13.6, J19.2
/Motor 2 (C1): J14.3, U1.8 (D5)
/Motor 2 (C2): J14.4, U1.3 (D15)
/Motor 2 (M1): J14.1, J20.1
/Motor 2 (M2): J14.6, J20.2
/RED1_EAR: J22.3, J26.2
/RED2_EAR: J23.1, J27.2
/SCK_EAR: J22.6, J23.6, J24.4, J25.4
/SD_EAR: J22.7, J23.7, J24.1, J25.1
/SIG_1: J3.2, U1.4 (D2)
/SIG_2: J3.1, U1.5 (D4)
/SIG_3: J4.2, U1.9 (D18)
/SIG_4: J4.1, U1.10 (D19)
/WS_EAR: J22.5, J23.5, J24.5, J25.5
GND: J1.2, J2.2, J3.5, J3.6, J4.5, J4.6, J5.2, J7.2, J8.1, J8.6, J9.1, J10.6, J10.9, J10.14, J10.20, J10.25, J10.30, J10.34, J10.39, J11.2, J12.3, J13.2, J14.2, J15.3, J16.3, J17.2, J21.4, J28.2, J29.2, J30.2, R2.2, R3.2, U1.2 (GND), U1.29 (GND)
GND_EAR: J22.4, J22.9, J23.9, J24.3, J24.6, J25.3, J26.4, J27.4

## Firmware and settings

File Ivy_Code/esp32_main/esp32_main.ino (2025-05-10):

#include <Arduino.h>
#include <Wire.h>

// I2C Address
#define ESP32_ADDRESS 0x77

// Motor control pins
#define IN1 33
#define IN2 25
#define IN3 26
#define IN4 27
#define ENA 32
#define ENB 14

// Encoder pins
#define C1A 23
#define C1B 13
#define C2A 5
#define C2B 15

// Servo PWM pins
#define E1 2
#define E2 4
#define A1 18
#define A2 19

// Servo configuration
const int servo_freq = 50;
const int servo_resolution = 12;
const int servo_channels[4] = {0, 1, 2, 3};
int servo_limits[2] = {0, 0};

// Motor parameters
const int DC_freq = 5000;
const int DC_resolution = 8;
const int DC_channels[2] = {4, 5};
const float ENC_COUNTS_PER_REV = 330.0;
const int SAMPLE_TIME_MS = 50;

// PID parameters
const float Kp[2] = {18.12, 18.44};
const float Ki[2] = {382.9, 382.15};

// Global variables
volatile int encoder_ticks[2] = {0, 0};
float target_speeds[2] = {0};
float current_speeds[2] = {0};
float integral_errors[2] = {0};
int motor_outputs[2] = {0};

// Servo angles
float servo_angles[4] = {90, 90, 130, 70}; // E1, E2, A1, A2

// Low-pass filter
class LowPassFilter {
  float alpha;
  float filtered;
public:
  LowPassFilter(float cutoff, float sampleRate) {
    float dt = 1.0 / sampleRate;
    float RC = 1.0 / (2 * 3.1416 * cutoff);
    alpha = dt / (RC + dt);
    filtered = 0;
  }

  float update(float input) {
    filtered += alpha * (input - filtered);
    return filtered;
  }
};

LowPassFilter speed_filters[2] = { LowPassFilter(10, 20), LowPassFilter(10, 20) };


// I2C data union
union {
  uint8_t bytes[8];
  float values[2];
} i2c_data;

// Encoder ISR
void IRAM_ATTR encoder1ISR() {
  bool dir = GPIO.in & (1 << C1B);
  encoder_ticks[0] += dir ? 1 : -1;
}

void IRAM_ATTR encoder2ISR() {
  bool dir = GPIO.in & (1 << C2B);
  encoder_ticks[1] += dir ? 1 : -1;
}

// Servo functions
void setupServos() {
  for(int i=0; i<4; i++) {
    ledcSetup(servo_channels[i], servo_freq, servo_resolution);
    ledcAttachPin((const int[]){E1, E2, A1, A2}[i], servo_channels[i]);
  }
  servo_set_range(500, 2400);
}

void servo_set_range(int low_us, int high_us) {
  servo_limits[0] = (low_us * (1 << servo_resolution)) / 20000;
  servo_limits[1] = (high_us * (1 << servo_resolution)) / 20000;
}

void writeServoAngle(int channel, float angle) {
  angle = constrain(angle, 0, 180);
  int duty = map(angle, 0, 180, servo_limits[0], servo_limits[1]);
  ledcWrite(servo_channels[channel], duty);
}

// Motor control
void setMotorDirection(int motor, int dir) {
  const int pins[2][2] = {{IN1, IN2}, {IN3, IN4}};
  digitalWrite(pins[motor][0], dir == 1);
  digitalWrite(pins[motor][1], dir == -1);
}

void updateMotorOutput(int motor) {
  motor_outputs[motor] = constrain(motor_outputs[motor], -255, 255);
  ledcWrite(DC_channels[motor], abs(motor_outputs[motor]));
  setMotorDirection(motor, motor_outputs[motor] > 0 ? 1 : (motor_outputs[motor] < 0 ? -1 : 0));
}

// PID calculation
void updatePID(int motor) {
  if(target_speeds[motor] == 0) {
    integral_errors[motor] = 0;
motor_outputs[motor] = 0;
    return;
  }

  float error = target_speeds[motor] - current_speeds[motor];
  integral_errors[motor] = constrain(integral_errors[motor] + error * SAMPLE_TIME_MS / 1000.0, -5, 3);
  
  float output = Kp[motor] * error + Ki[motor] * integral_errors[motor];
  motor_outputs[motor] = constrain(output, -255, 255);
}

// I2C handler
void receiveEvent(int byteCount) {
  if(byteCount >= 9) {
    uint8_t cmd = Wire.read();
    if(cmd < 3) {
      for(int i=0; i<8; i++) i2c_data.bytes[i] = Wire.read();
      
      if(cmd == 0) {
        target_speeds[0] = i2c_data.values[0];
        target_speeds[1] = i2c_data.values[1];
      } else {
        int startIdx = cmd == 1 ? 0 : 2;
        for(int i=0; i<2; i++) {
          servo_angles[startIdx+i] = constrain(i2c_data.values[i], 0, 180);
          writeServoAngle(startIdx+i, servo_angles[startIdx+i]);
        }
      }
    }
  }
}

void setup() {
  // I2C setup
  Wire.begin(ESP32_ADDRESS);
  Wire.onReceive(receiveEvent);
  
  // Motor control pins
  pinMode(IN1, OUTPUT); pinMode(IN2, OUTPUT);
  pinMode(IN3, OUTPUT); pinMode(IN4, OUTPUT);
  
  // PWM setup
  for(int i=0; i<2; i++) {
    ledcSetup(DC_channels[i], DC_freq, DC_resolution);
    ledcAttachPin((const int[]){ENA, ENB}[i], DC_channels[i]);
  }
  
  // Encoder setup
  pinMode(C1A, INPUT_PULLUP);
  pinMode(C1B, INPUT_PULLUP);
  pinMode(C2A, INPUT_PULLUP);
  pinMode(C2B, INPUT_PULLUP);
  attachInterrupt(digitalPinToInterrupt(C1A), encoder1ISR, FALLING);
  attachInterrupt(digitalPinToInterrupt(C2A), encoder2ISR, FALLING);
  
  // Servo setup
  setupServos();
  for(int i=0; i<4; i++)
    writeServoAngle(i, servo_angles[i]);
}

void loop() {
  static unsigned long lastUpdate = 0;
  if(millis() - lastUpdate >= SAMPLE_TIME_MS) {
    // Update speed calculations
    noInterrupts();
    int ticks[] = {encoder_ticks[0], encoder_ticks[1]};
    encoder_ticks[0] = encoder_ticks[1] = 0;
    interrupts();
    
    for(int i=0; i<2; i++) {
      float rpm = (ticks[i] * 60000.0) / (ENC_COUNTS_PER_REV * SAMPLE_TIME_MS);
      current_speeds[i] = speed_filters[i].update(rpm);
    }
    
    // Update PID and motor outputs
    for(int i=0; i<2; i++) {
      updatePID(i);
      updateMotorOutput(i);
    }
    
    lastUpdate = millis();
  }
}

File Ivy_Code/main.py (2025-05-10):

from src.utility.utils import *

from multiprocessing import Process
        
def lcd_process():
    while running.is_set():
        try:
            if lcd.current_express == "idle_optimus" or lcd.current_express == "idle_optimus2":
                if lcd.current_index == 1:
                    lcd.fps = 10
                elif lcd.current_index == len(lcd.package[lcd.current_express]) - 1:
                    lcd.fps = 16

            expression = express_dictionary[express.value]
            lcd.show_expression(expression)

            if "idle_" in expression and lcd.current_index == len(lcd.package[lcd.current_express]) - 1:
                with express.get_lock():
                    express.value = 0

            if lcd.current_express == "idle5" and lcd.current_index == 0:
                look_around.set()
                time.sleep(0.2)

            if express.value == 25 and lcd.current_index == len(lcd.package[lcd.current_express]) - 1:
                lcd.switch(on = False)

            if lcd.current_express == "paint_to_idle" and lcd.current_index == 14:
                time.sleep(10)

        except KeyboardInterrupt:
            break

        except Exception as e:
            err.set()
            print(e)
        
def battery_process():
    while running.is_set():
        try:
            data = com.read_serial()
            if data != "":
                if "Battery" in data:
                    voltage = data.split(":")[-1]
                    voltage = float(voltage)
                    battery_percent = - 27.318 * voltage * voltage + 703.36 * voltage - 4428.1
                    with battery.get_lock():
                        battery.value = max(5, min(100, int(battery_percent)))

                    if battery.value <= 20:
                        with low_battery_count.get_lock():
                            low_battery_count.value = low_battery_count.value + 1
                    else:
                        with low_battery_count.get_lock():
                            low_battery_count.value = 0
        except KeyboardInterrupt:
            break

        except Exception as e:
            err.set()
            print(e)

def upload_image_process():
    while running.is_set():
        try:
            if state_dictionary[state.value] == "go around" or state_dictionary[state.value] == "follow": 
                frame = cam.get_image()
                encoded_image = cam.encode_image(frame, quality = 40)
                mqtt.upload_image(encoded_image)

        except KeyboardInterrupt:
            break
        
        except Exception as e:
            err.set()
            print(e)

def stop_holding_process():
    this_timer = time.perf_counter()
    stop_holding = True
    while running.is_set():
        try:
            if not acting.is_set():
                if stop_holding:
                    if time.perf_counter() - this_timer >= 0.25:
                        if com.ll.value == 0 and com.rl.value == 0 and com.le.value  == 0 and com.re.value == 0:
                            com.stop_all()
                            stop_holding = False
                        this_timer = time.perf_counter()
                else:
                    if time.perf_counter() - this_timer >= 3.0:
                        if com.ll.value == 0 and com.rl.value == 0 and com.le.value == 0 and com.re.value  == 0:
                            com.set_ear(0, 0)
                            com.set_leg(0, 0)
                            stop_holding = True
                        this_timer = time.perf_counter()
            else:
                stop_holding = True
                this_timer = time.perf_counter()

        except KeyboardInterrupt:
            break

        except Exception as e:
            err.set()
            print(e)

def main():
    acting.set()

    # Create a process for battery calculation
    battery_instance = Process(target = battery_process)
    battery_instance.start()

    # Create a process for image capturing
    upload_image_instance = Thread(target = upload_image_process)
    upload_image_instance.start()

    # Create a process for the lcd display
    lcd_instance = Process(target = lcd_process)

    touch_setup()
    vc_setup()

    com.send_motor_speed(0, 0)
    com.set_ear(0, 0)
    com.set_leg(0, 0)

    # Mumble timing
    sound_timing = time.perf_counter()
    sound_waiting = random.randint(180, 240)

    do_hi = False
    do_sigh = False

    friendly_value = friendly.value
    if friendly_value < 30:
        do_sigh = True
    elif friendly_value < 50:
        do_sigh = random.choices([True, False], [0.3, 0.7])[0]
    else:
        do_sigh = False
    
    if do_sigh:
        sigh()
        lcd_instance.start()
        for i in range(100, -1, -1):
            rgb.light = i
            rgb.set_battery()
            time.sleep(0.04)
        
    else:
        do_hi = random.choices([True, False], [0.8, 0.2])[0]
        hi()
        lcd_instance.start()
    
    rgb.light = 100
    rgb.set_battery()

    if do_hi:
        which_leg = random.choice([1, -1])
        range_leg(0, 15 * which_leg, 0 , -15 * which_leg, 100, 0.6)
        time.sleep(2)
        range_leg(15 * which_leg, 0 , -15 * which_leg, 0, 100, 0.6)

    acting.clear()

    # Stop holding process
    stop_holding_instance = Process(target = stop_holding_process)
    stop_holding_instance.start()

    try:  
        while running.is_set():
            try:
                if look_around.is_set():
                    acting.set()
                    play_sound("/home/pi/Ivy/src/speaker/audio_package/look_around.wav", wait = True)
                    look_around.clear()
                    acting.clear()

                if low_battery_count.value >= 8:
                    if not acting.is_set():
                        low_battery()

                        with low_battery_count.get_lock():
                            low_battery_count.value = 0
                    else:
                        with low_battery_count.get_lock():
                            low_battery_count.value = 4

                if battery.value != rgb.light:
                    rgb.light = battery.value 
                    if not acting.is_set():
                        rgb.set_battery()

                if state_dictionary[state.value] == "stand still":
                    # Mumble
                    if time.perf_counter() - sound_timing >= sound_waiting:
                        if not acting.is_set():
                            acting.set()
                            sound_timing = time.perf_counter()
                            sound_waiting = random.randint(180, 240)
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
